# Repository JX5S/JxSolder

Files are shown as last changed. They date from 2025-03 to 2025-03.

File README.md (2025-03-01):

# Do not order the board, or blindly copy the design, there are several known issues. Namely:
- USB-PD doesn't work. I thought I could do dead battery the way I did, but it's not a good way to do it, use PA9 and PA10 instead
- Display reset needs to be wired via an RC filter to 3.3V
- Vref needs to be connected up
- Button logic is flipped - so DFU firmware upload doesn't work
- There are unidirectional transils on the input - which blow up when incorrect polarity is plugged in. Should be replaced by bidirectional transils, the ideal diodes will protect the input
- There aren't dedicated I2C pullups, which limits speed

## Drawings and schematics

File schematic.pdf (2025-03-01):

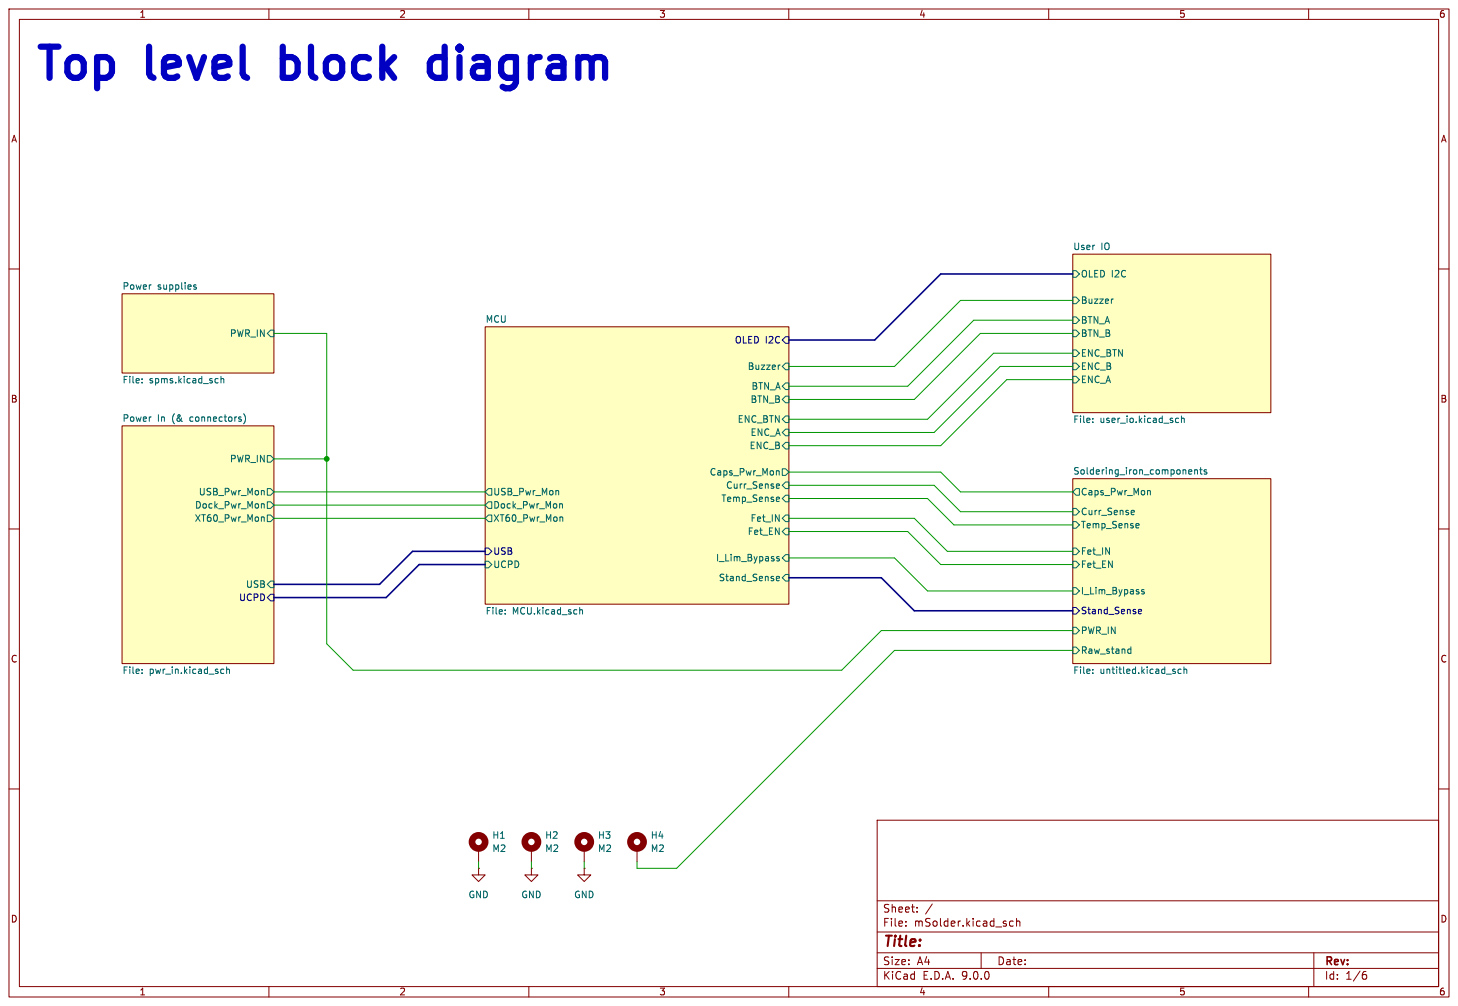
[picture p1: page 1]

H2 M2 H1 M2 Top level block diagram

Id: 1/6 Title: File: mSolder.kicad_sch Sheet: /

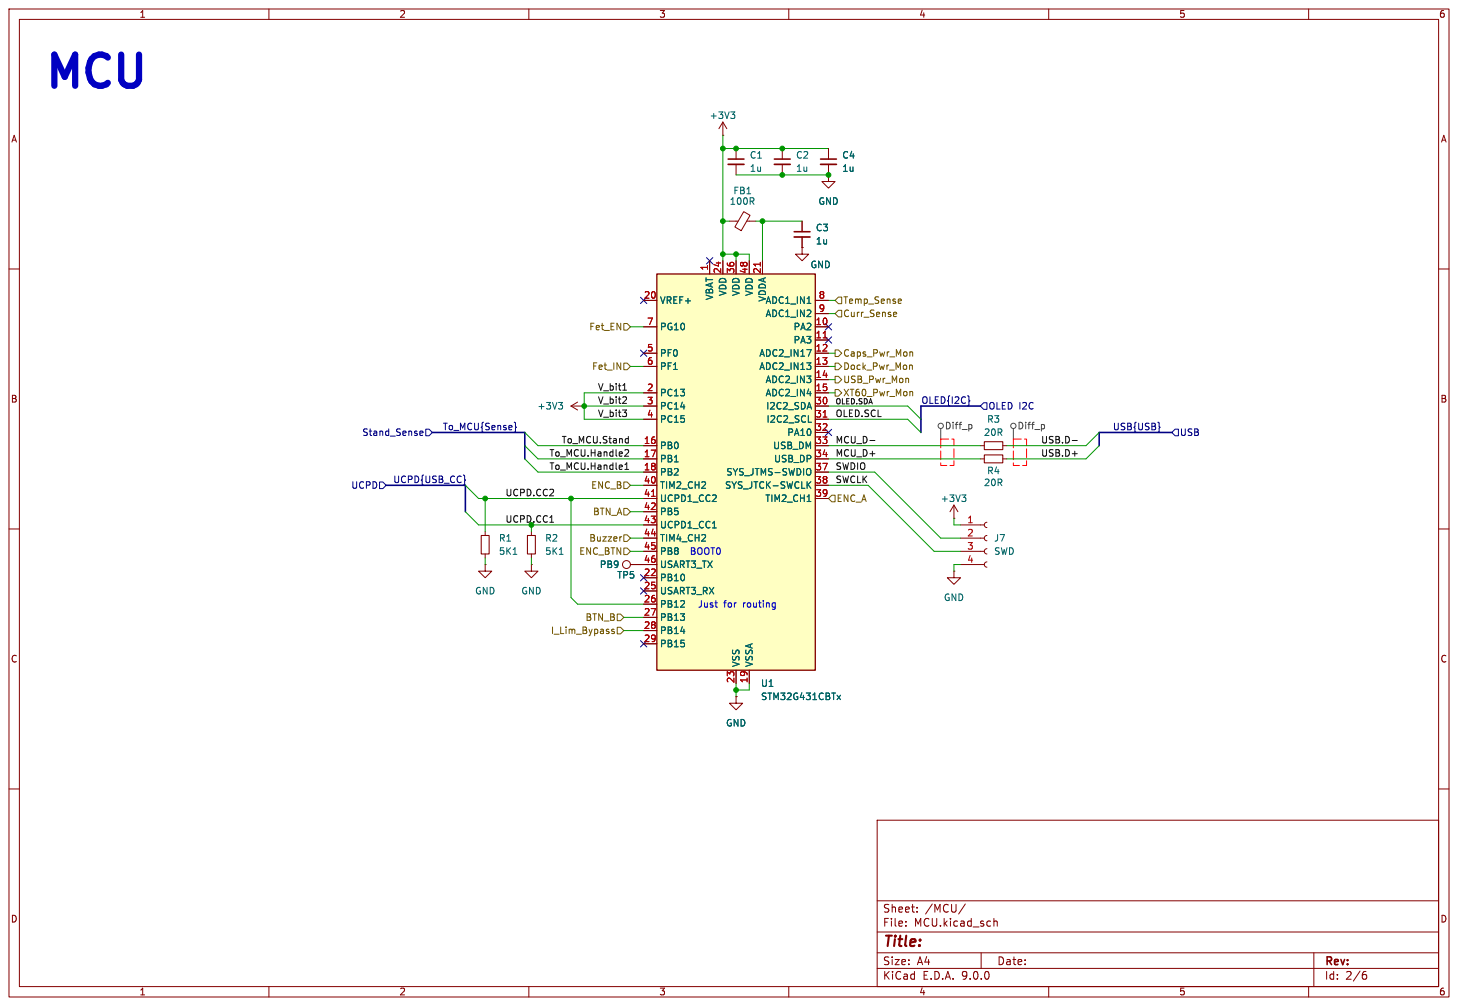
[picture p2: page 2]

1 VDD 24 VDD 36 VSS 23 VDD 48 VSSA 19 VDDA 21 ADC1_IN1 8 ADC1_IN2 9 PA2 10 PA3 11 ADC2_IN17 12 ADC2_IN13 13 ADC2_IN3 14 ADC2_IN4 15

Id: 2/6 Title: File: MCU.kicad_sch Sheet: /MCU/

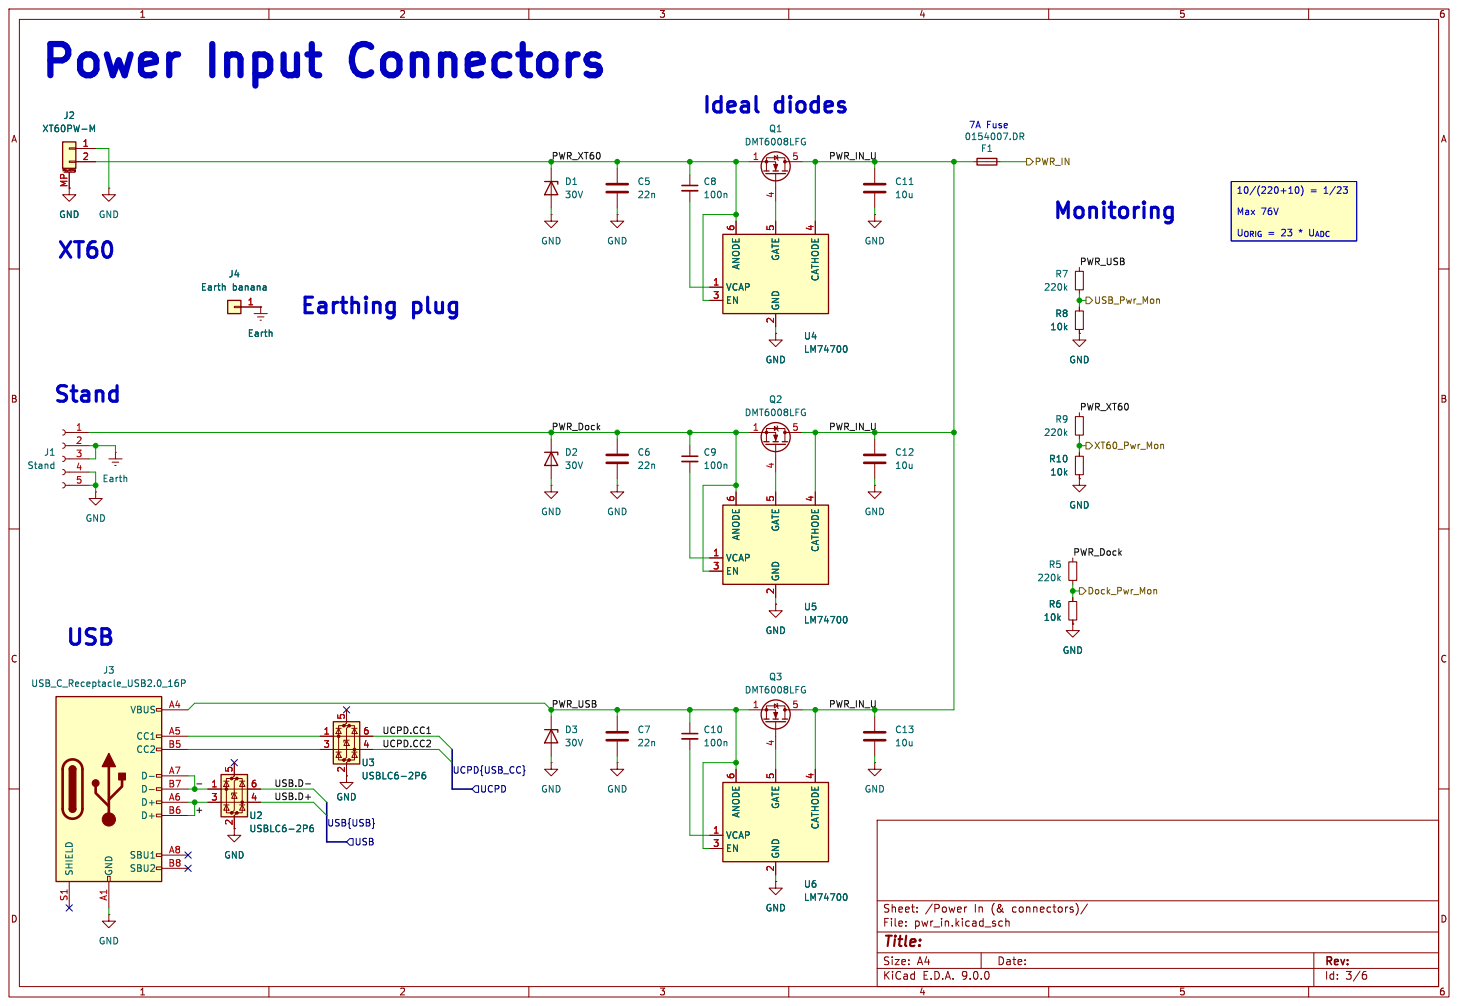
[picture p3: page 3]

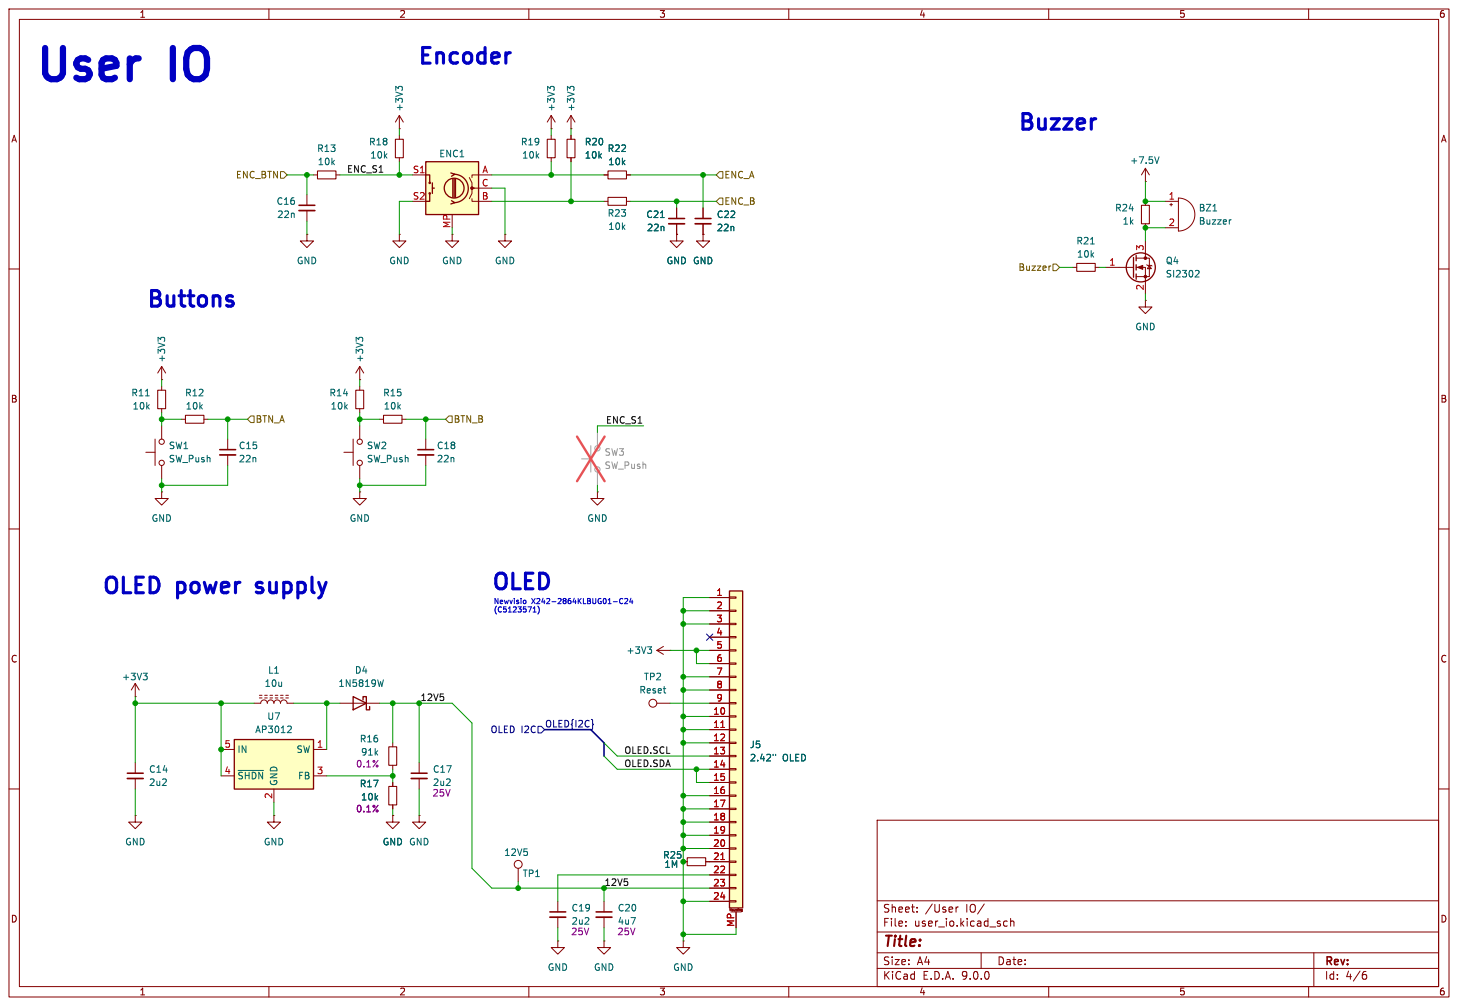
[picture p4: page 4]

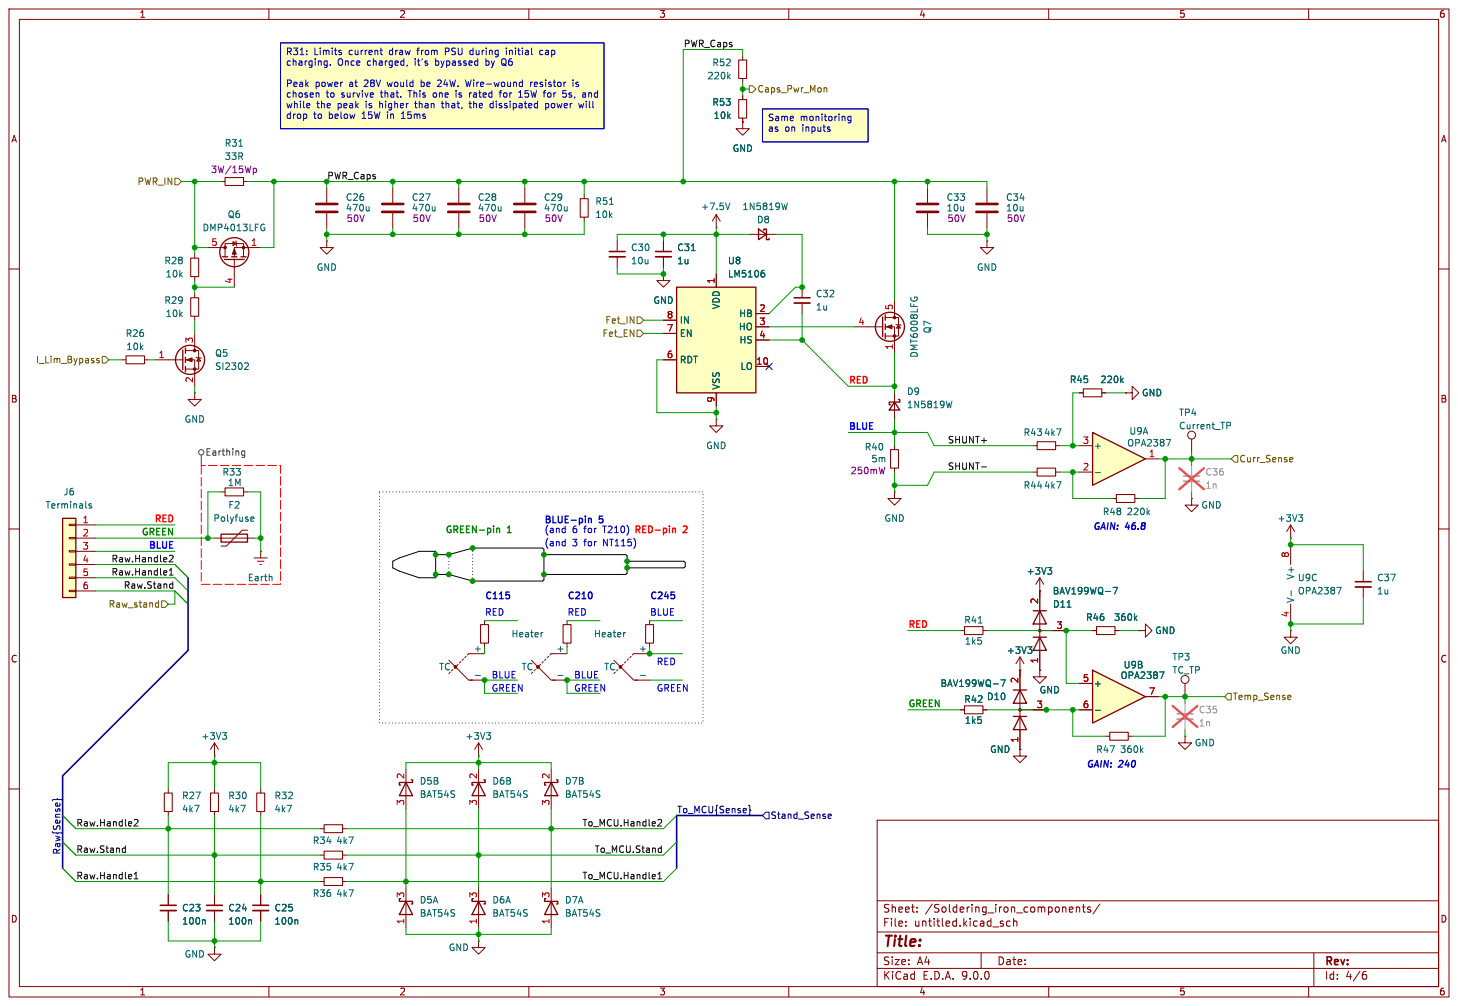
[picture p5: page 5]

Id: 4/6 Title: File: untitled.kicad_sch Sheet: /Soldering_iron_components/ R33

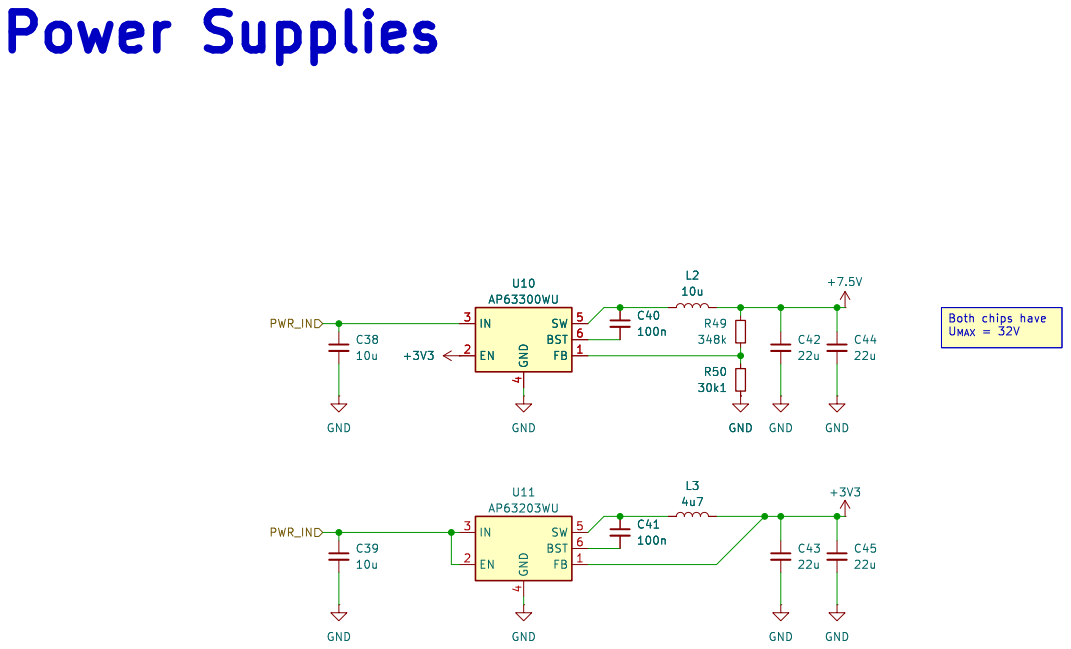
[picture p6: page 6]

Both chips have U_{MAX} = 32V Power Supplies

4 SW 5 BST 6 FB 1 U10 AP63300WU GND

4 SW 5 BST 6 FB 1 U11 AP63203WU GND

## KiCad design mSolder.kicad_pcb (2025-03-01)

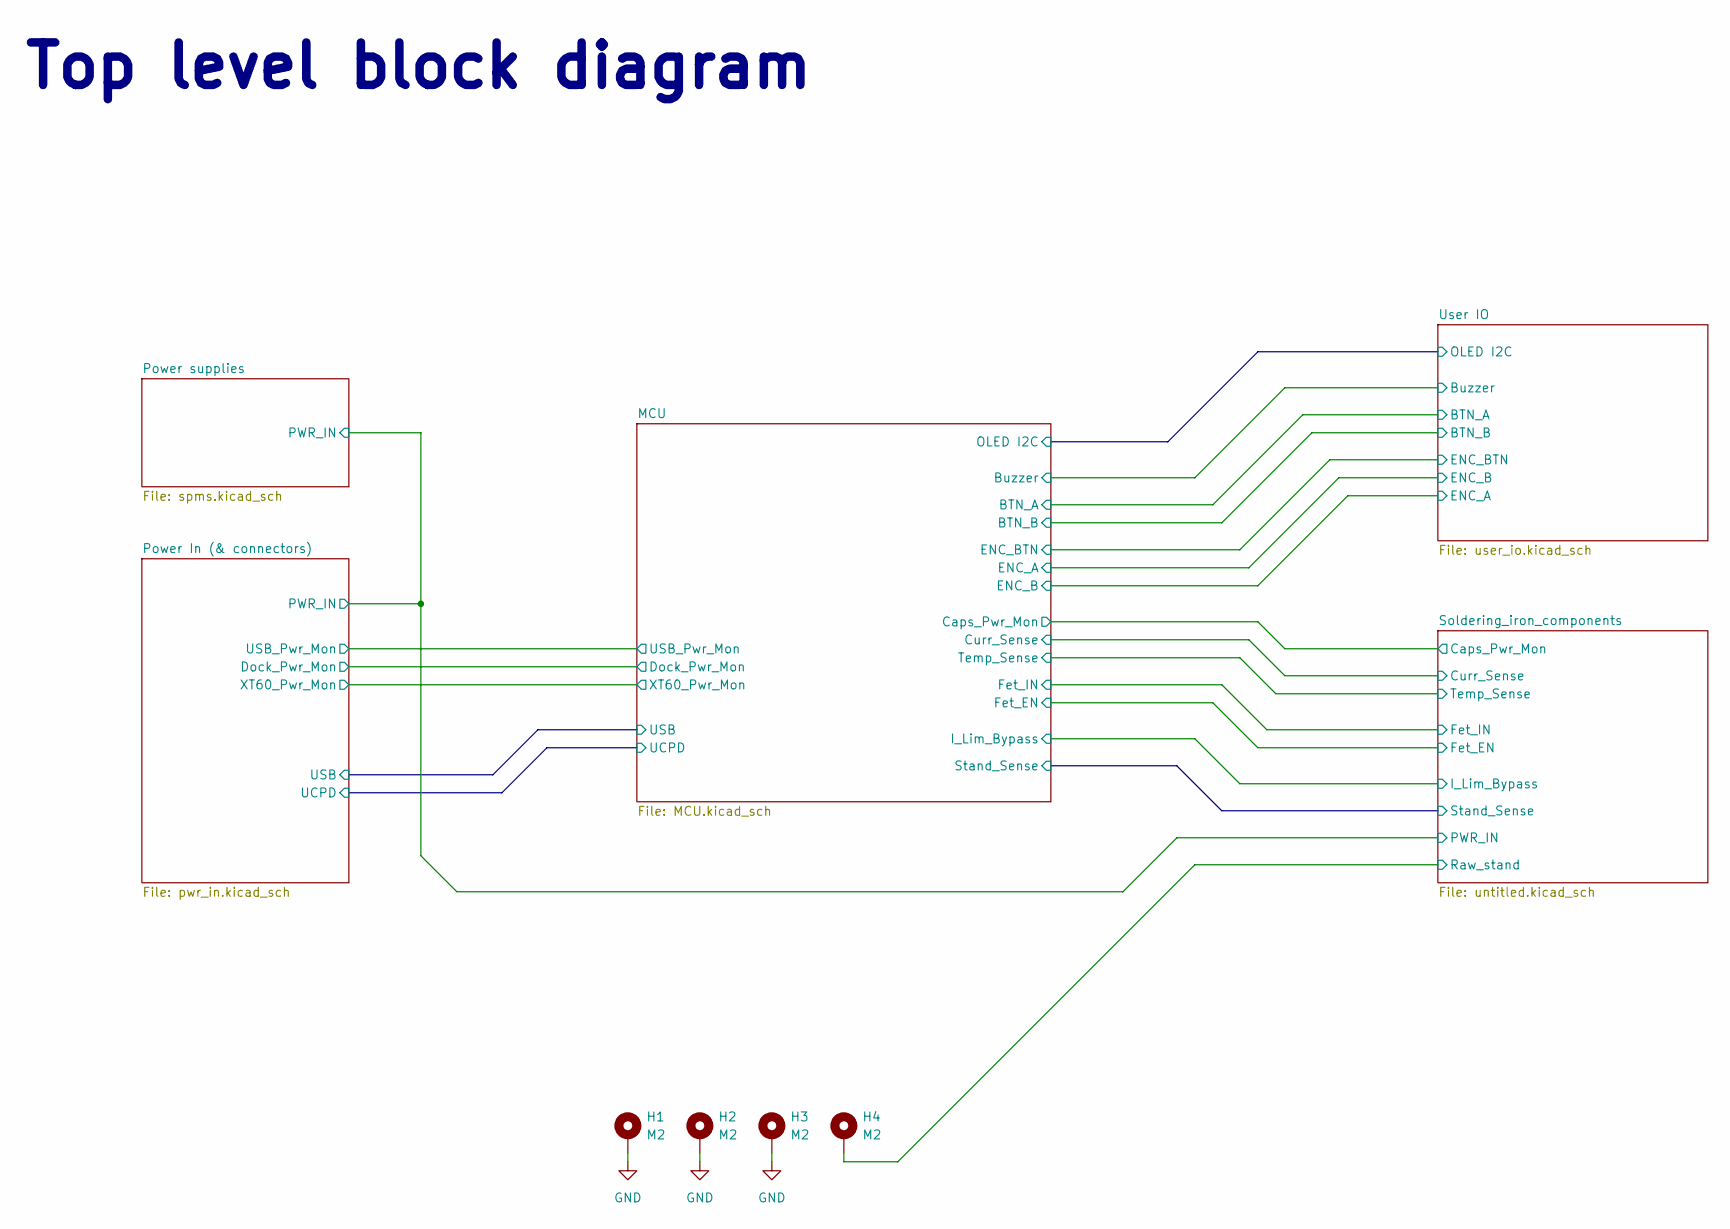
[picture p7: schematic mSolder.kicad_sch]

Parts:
H1, H2, H3, H4: M2; M2 solder nut; LCSC C3020134

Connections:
/Soldering_iron_components/Raw.Stand: H4.1; also elsewhere on the board
GND: H1.1, H2.1, H3.1; also elsewhere on the board

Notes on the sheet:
Top level block diagram

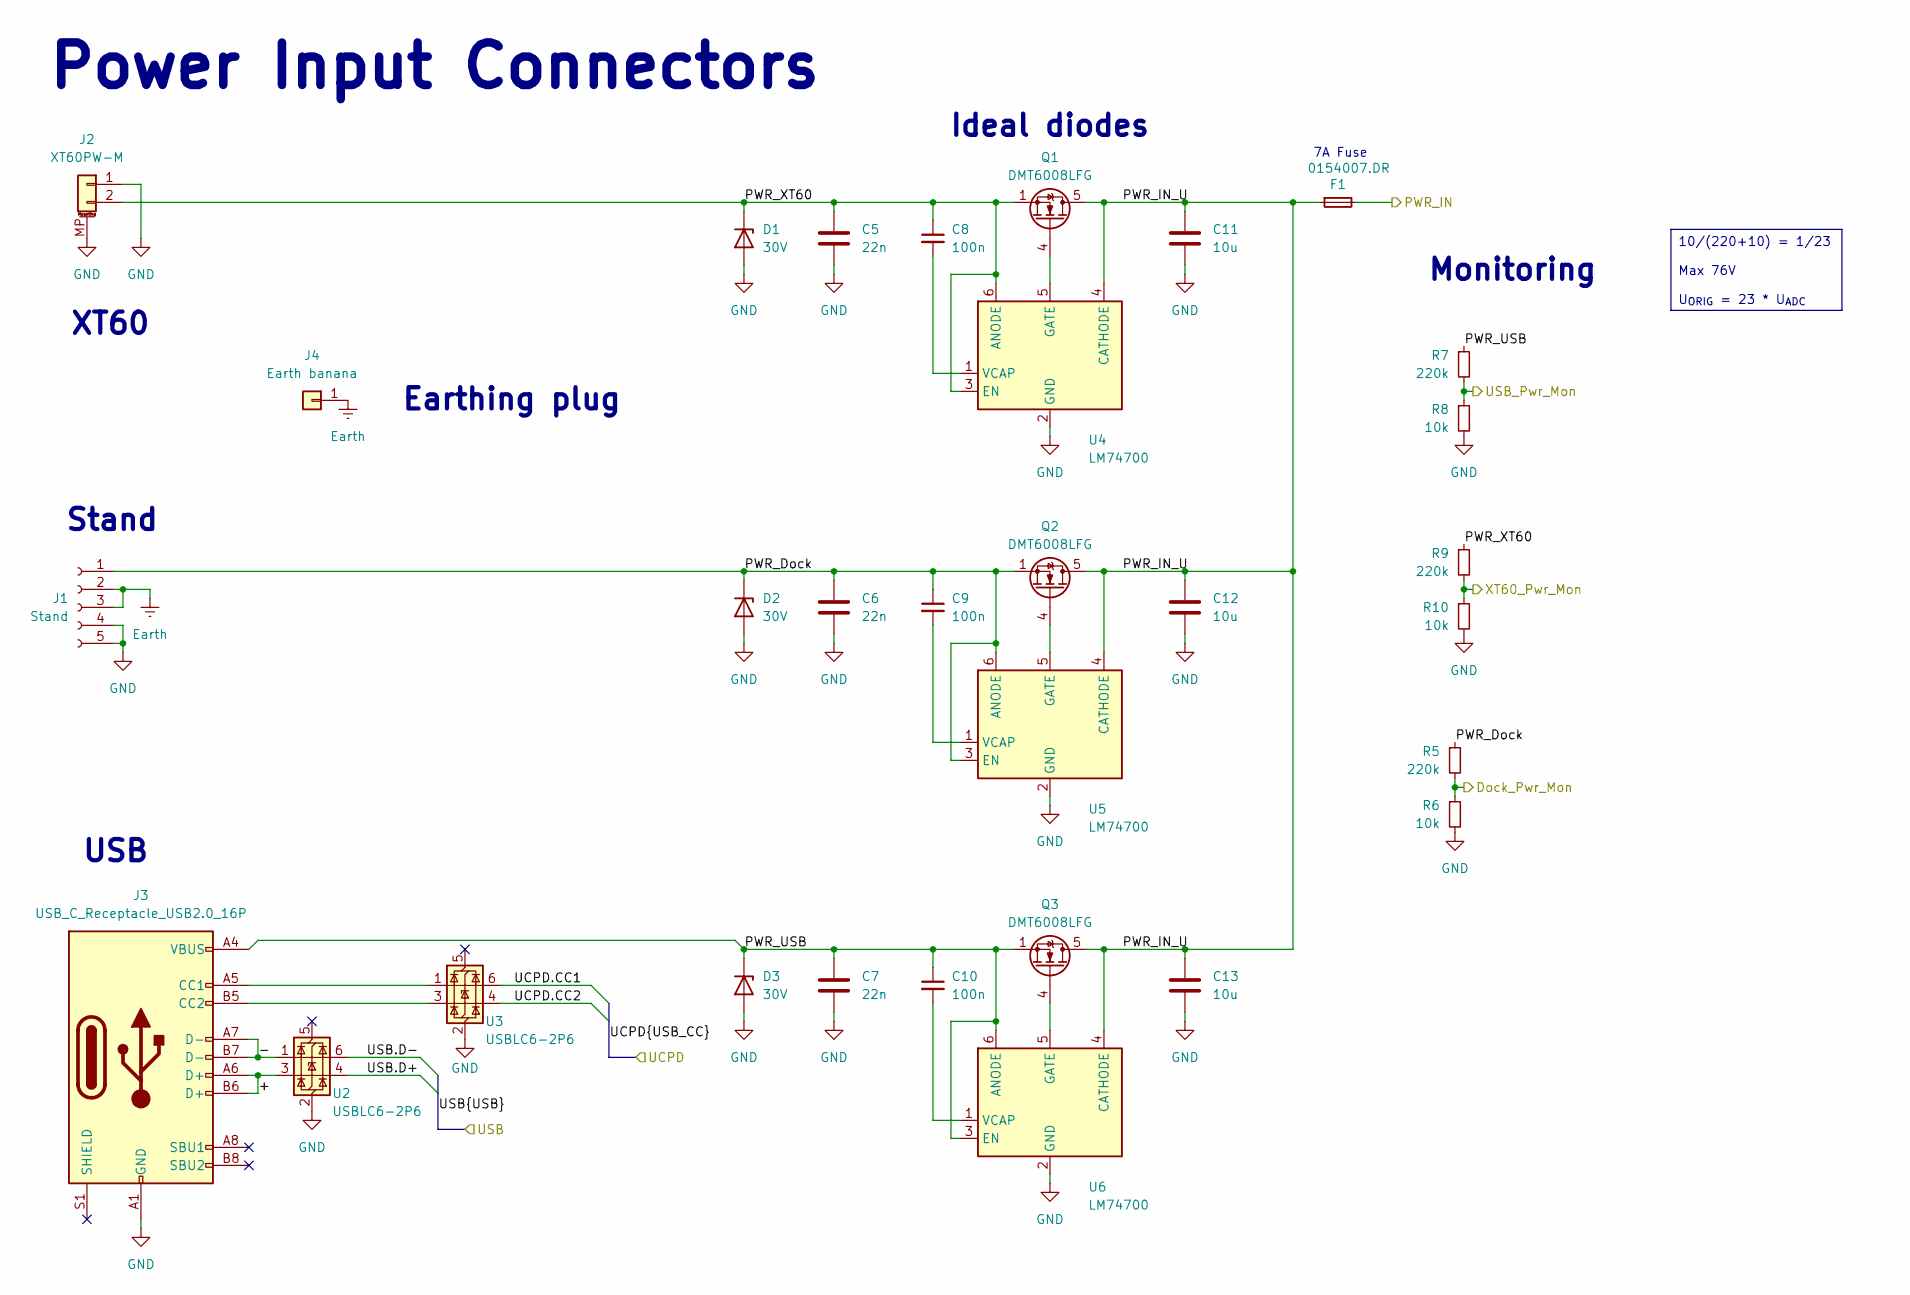
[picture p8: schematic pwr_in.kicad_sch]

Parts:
C5, C6, C7: 22n; C_0603_1608Metric; LCSC C21122
C8, C9, C10: 100n; C_0603_1608Metric; LCSC C1591
C11, C12, C13: 10u; C_1206_3216Metric; LCSC C13585
D1, D2, D3: 30V; D_SMA; LCSC C132943
F1: 0154007.DR; 0154100DR; Mouser Part Number 576-0154007.DR
J1: Stand; 1473969.1
J2: XT60PW-M; LCSC C98732
J3: USB_C_Receptacle_USB2.0_16P; USB_C_Receptacle_G-Switch_GT-USB-7010ASV; LCSC C963413
J4: Earth banana; CONN-TH_24.243.2; LCSC C7437324
Q1, Q2, Q3: DMT6008LFG; Diodes_PowerDI3333-8; LCSC C461111
R5, R7, R9: 220k; R_0603_1608Metric; LCSC C861231
R6, R8, R10: 10k; R_0603_1608Metric; LCSC C95204
U2, U3: USBLC6-2P6; SOT-666; LCSC C15999
U4, U5, U6: LM74700; SOT-23-6; LCSC C7589230

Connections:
/MCU/Dock_Pwr_Mon: R5.2, R6.1; also elsewhere on the board
/MCU/UCPD.CC1: U3.6 (I/O1); also elsewhere on the board
/MCU/UCPD.CC2: U3.4 (I/O2); also elsewhere on the board
/MCU/USB.D+: U2.4 (I/O2); also elsewhere on the board
/MCU/USB.D-: U2.6 (I/O1); also elsewhere on the board
/MCU/USB_Pwr_Mon: R7.2, R8.1; also elsewhere on the board
/MCU/XT60_Pwr_Mon: R9.2, R10.1; also elsewhere on the board
/Power In (& connectors)/+: J3.A6 (D+), J3.B6 (D+), U2.3 (I/O2)
/Power In (& connectors)/-: J3.A7 (D-), J3.B7 (D-), U2.1 (I/O1)
/Power In (& connectors)/PWR_Dock: C6.1, C9.1, D2.1 (K), J1.1, Q2.1 (S), Q2.2 (S), Q2.3 (S), R5.1, U5.3 (EN), U5.6 (ANODE)
/Power In (& connectors)/PWR_IN: F1.2; also elsewhere on the board
/Power In (& connectors)/PWR_IN_U: C11.1, C12.1, C13.1, F1.1, Q1.5 (D), Q2.5 (D), Q3.5 (D), U4.4 (CATHODE), U5.4 (CATHODE), U6.4 (CATHODE)
/Power In (& connectors)/PWR_USB: C7.1, C10.1, D3.1 (K), J3.A4 (VBUS), J3.A9 (VBUS), J3.B4 (VBUS), J3.B9 (VBUS), Q3.1 (S), Q3.2 (S), Q3.3 (S), R7.1, U6.3 (EN), U6.6 (ANODE)
/Power In (& connectors)/PWR_XT60: C5.1, C8.1, D1.1 (K), J2.2, Q1.1 (S), Q1.2 (S), Q1.3 (S), R9.1, U4.3 (EN), U4.6 (ANODE)
Earth: J1.2, J1.3, J4.1; also elsewhere on the board
GND: C5.2, C6.2, C7.2, C11.2, C12.2, C13.2, D1.2 (A), D2.2 (A), D3.2 (A), J1.4, J1.5, J2.1, J2.MP (MountPin), J3.A1 (GND), J3.A12 (GND), J3.B1 (GND), J3.B12 (GND), R6.2, R8.2, R10.2, U2.2 (GND), U3.2 (GND), U4.2 (GND), U5.2 (GND), U6.2 (GND); also elsewhere on the board
unnamed: J3.A5 (CC1), U3.1 (I/O1)
unnamed: J3.B5 (CC2), U3.3 (I/O2)
unnamed: Q1.4 (G), U4.5 (GATE)
unnamed: Q2.4 (G), U5.5 (GATE)
unnamed: Q3.4 (G), U6.5 (GATE)
unnamed: C8.2, U4.1 (VCAP)
unnamed: C9.2, U5.1 (VCAP)
unnamed: C10.2, U6.1 (VCAP)

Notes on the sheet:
Monitoring
Ideal diodes
Power Input Connectors
XT60
Earthing plug
USB
Stand
7A Fuse
10/(220+10) = 1/23 Max 76V U_{ORIG} = 23 * U_{ADC}

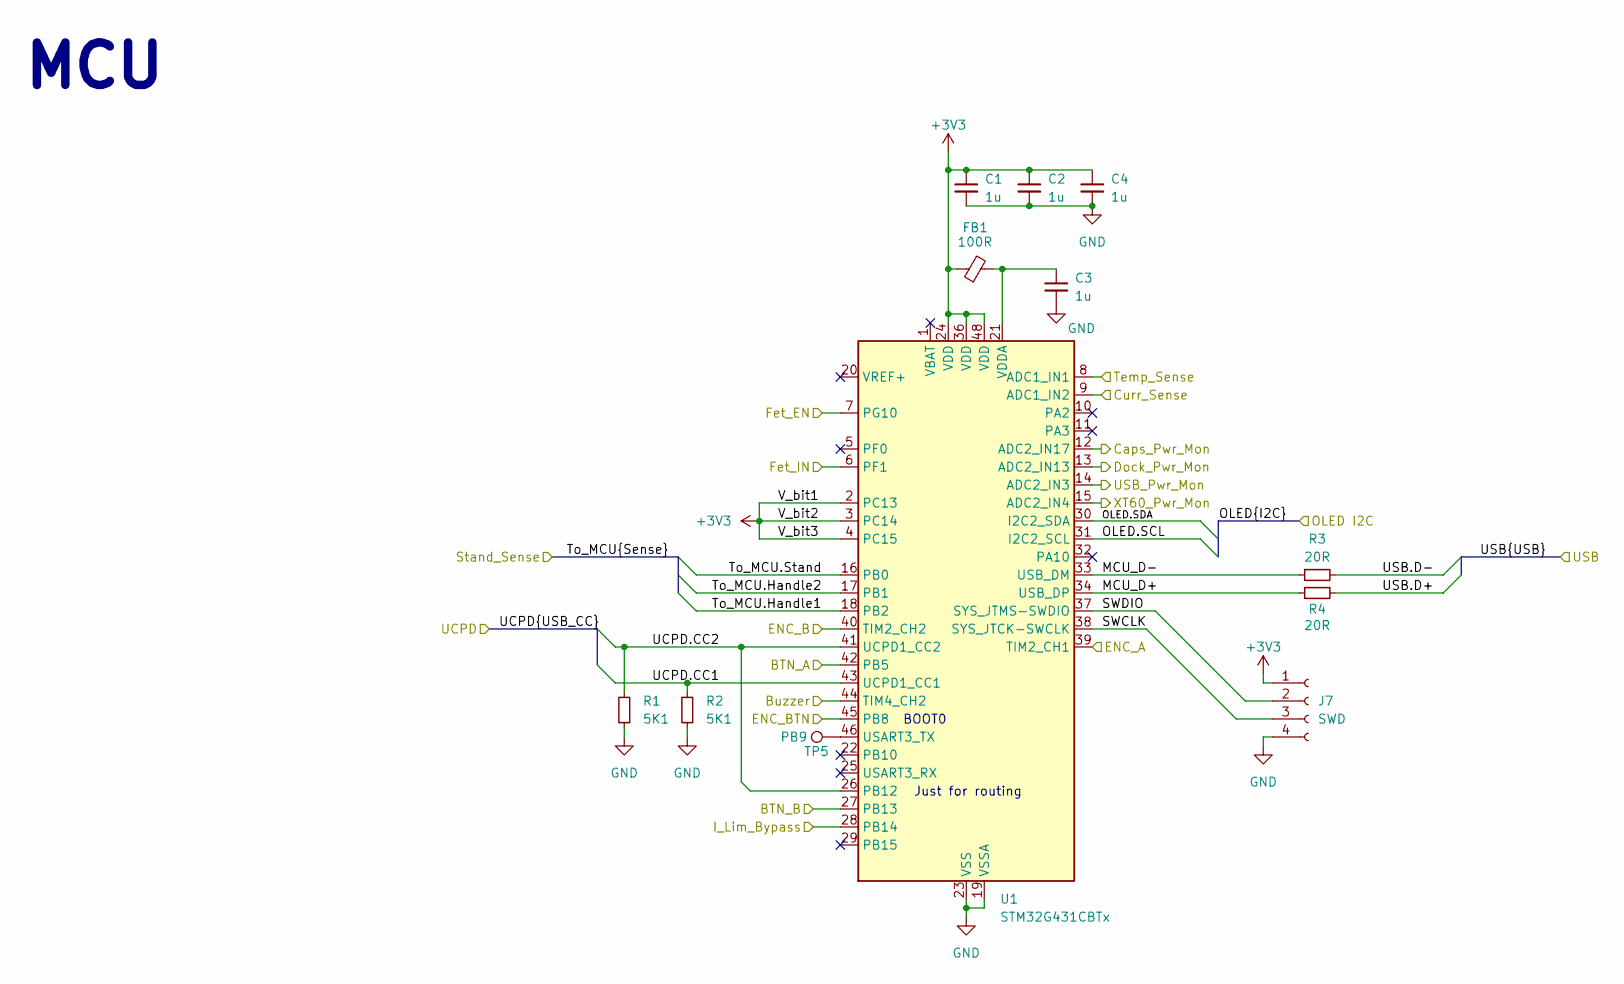
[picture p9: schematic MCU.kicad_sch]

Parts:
C1, C2, C3, C4: 1u; C_0603_1608Metric; LCSC C15849
FB1: 100R; R_0603_1608Metric; LCSC C107332
J7: SWD; PinHeader_1x04_P2.54mm_Vertical; LCSC C2691448
R1, R2: 5K1; R_0603_1608Metric; LCSC C105580
R3, R4: 20R; R_0603_1608Metric; LCSC C125758
TP5: PB9; TestPoint_Pad_D1.0mm
U1: STM32G431CBTx; LQFP-48_7x7mm_P0.5mm; LCSC C529355

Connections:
+3V3: C1.1, C2.1, C4.1, FB1.1, J7.1, U1.2 (PC13), U1.3 (PC14), U1.4 (PC15), U1.24 (VDD), U1.36 (VDD), U1.48 (VDD); also elsewhere on the board
/MCU/BTN_A: U1.42 (PB5); also elsewhere on the board
/MCU/BTN_B: U1.27 (PB13); also elsewhere on the board
/MCU/Buzzer: U1.44 (PB7); also elsewhere on the board
/MCU/Caps_Pwr_Mon: U1.12 (ADC2_IN17); also elsewhere on the board
/MCU/Curr_Sense: U1.9 (ADC1_IN2); also elsewhere on the board
/MCU/Dock_Pwr_Mon: U1.13 (ADC2_IN13); also elsewhere on the board
/MCU/ENC_A: U1.39 (TIM2_CH1); also elsewhere on the board
/MCU/ENC_B: U1.40 (TIM2_CH2); also elsewhere on the board
/MCU/ENC_BTN: U1.45 (PB8); also elsewhere on the board
/MCU/Fet_EN: U1.7 (PG10); also elsewhere on the board
/MCU/Fet_IN: U1.6 (PF1); also elsewhere on the board
/MCU/I_Lim_Bypass: U1.28 (PB14); also elsewhere on the board
/MCU/MCU_D+: R4.1, U1.34 (USB_DP)
/MCU/MCU_D-: R3.1, U1.33 (USB_DM)
/MCU/OLED.SCL: U1.31 (I2C2_SCL); also elsewhere on the board
/MCU/OLED.SDA: U1.30 (I2C2_SDA); also elsewhere on the board
/MCU/SWCLK: J7.3, U1.38 (SYS_JTCK-SWCLK)
/MCU/SWDIO: J7.2, U1.37 (SYS_JTMS-SWDIO)
/MCU/Temp_Sense: U1.8 (ADC1_IN1); also elsewhere on the board
/MCU/To_MCU.Handle1: U1.18 (PB2); also elsewhere on the board
/MCU/To_MCU.Handle2: U1.17 (PB1); also elsewhere on the board
/MCU/To_MCU.Stand: U1.16 (PB0); also elsewhere on the board
/MCU/UCPD.CC1: R2.2, U1.43 (UCPD1_CC1); also elsewhere on the board
/MCU/UCPD.CC2: R1.2, U1.26 (PB12), U1.41 (UCPD1_CC2); also elsewhere on the board
/MCU/USB.D+: R4.2; also elsewhere on the board
/MCU/USB.D-: R3.2; also elsewhere on the board
/MCU/USB_Pwr_Mon: U1.14 (ADC2_IN3); also elsewhere on the board
/MCU/XT60_Pwr_Mon: U1.15 (ADC2_IN4); also elsewhere on the board
GND: C1.2, C2.2, C3.2, C4.2, J7.4, R1.1, R2.1, U1.19 (VSSA), U1.23 (VSS), U1.35 (VSS), U1.47 (VSS); also elsewhere on the board
unnamed: TP5.1, U1.46 (USART3_TX)
unnamed: C3.1, FB1.2, U1.21 (VDDA)

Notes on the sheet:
BOOT0
Just for routing
MCU

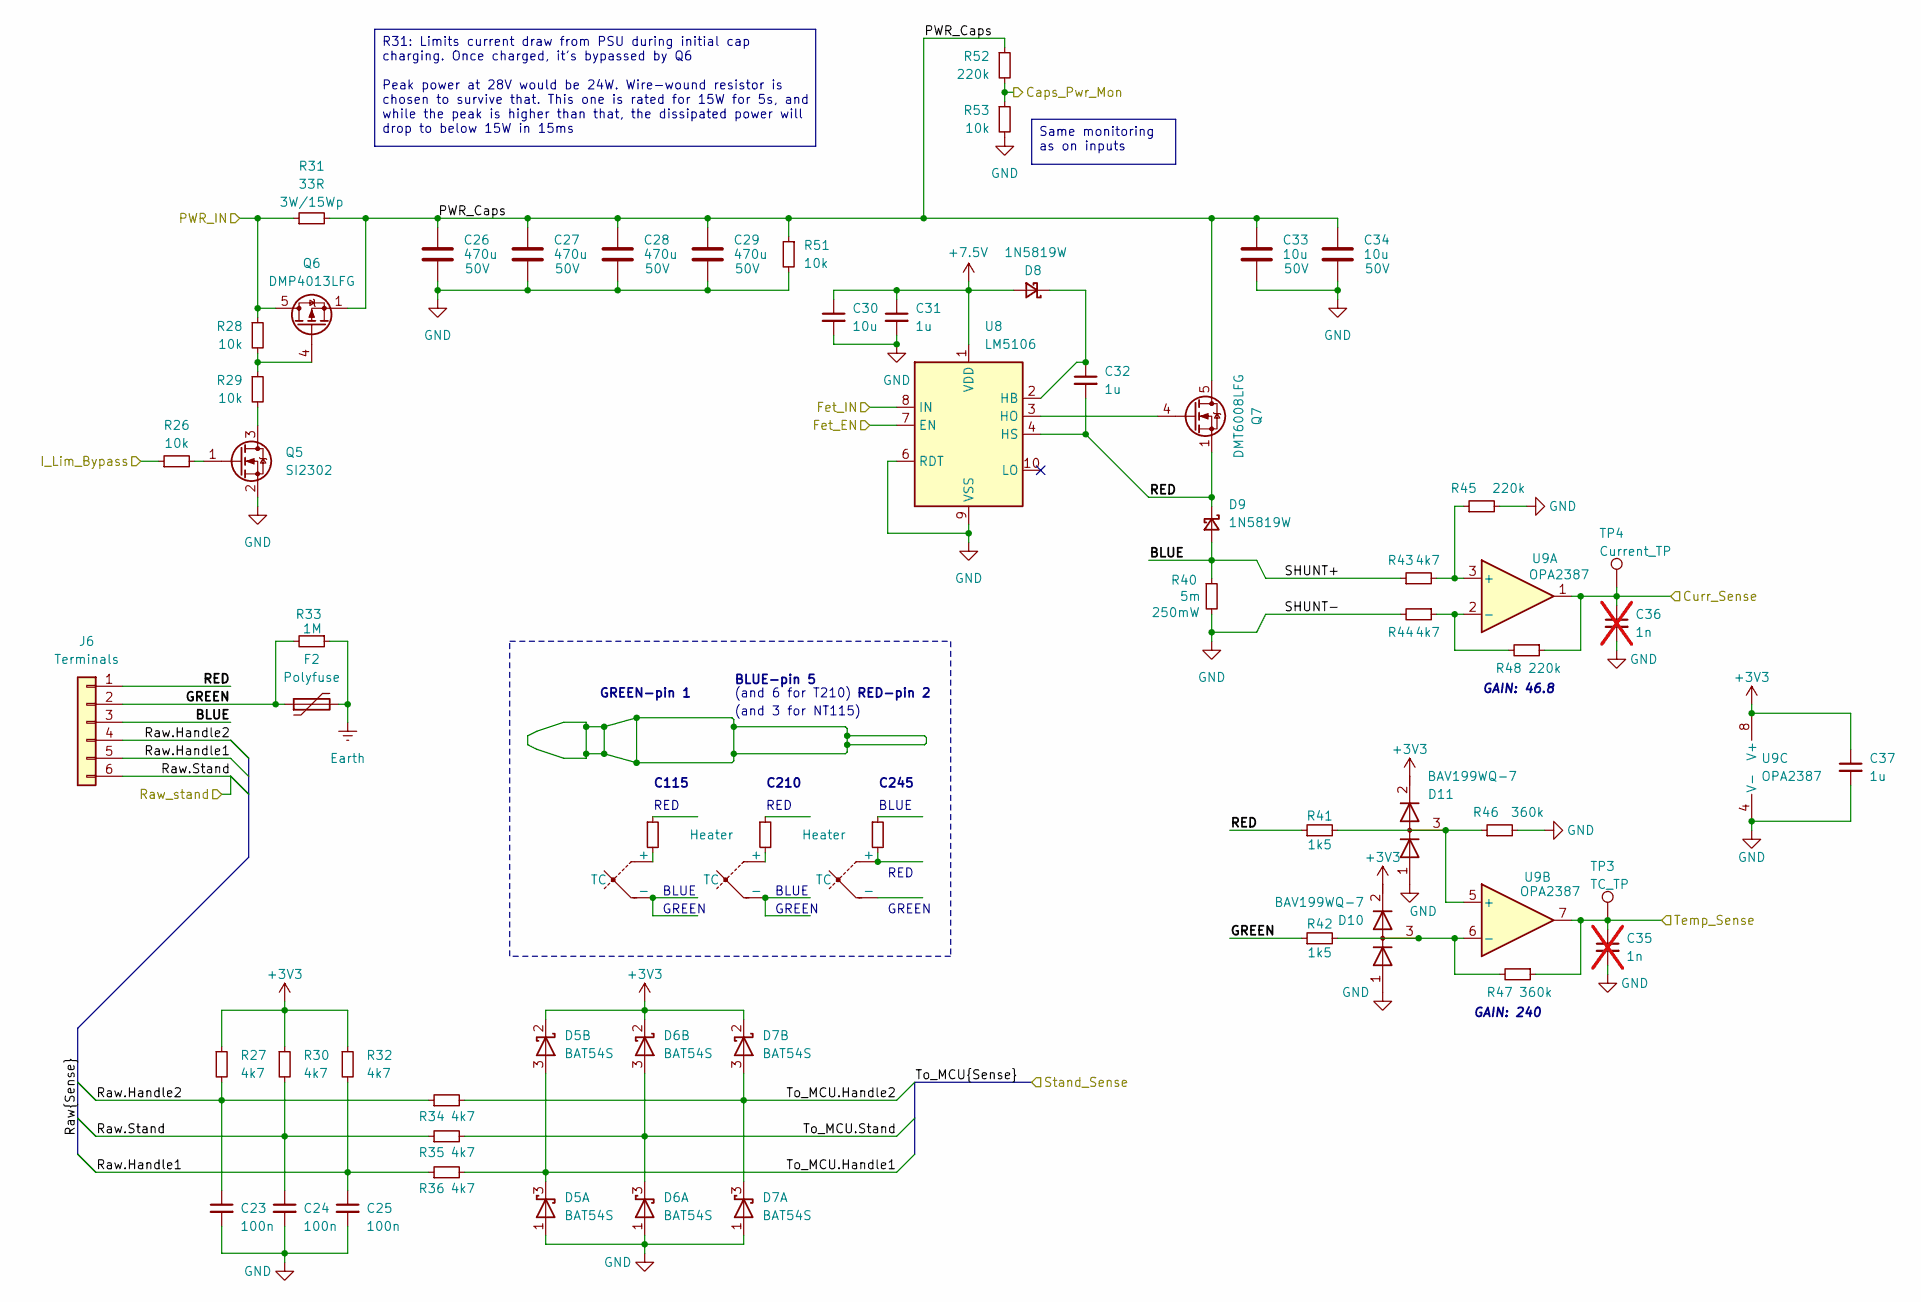
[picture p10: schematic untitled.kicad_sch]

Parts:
C23, C24, C25: 100n; C_0603_1608Metric; Manufacturer_Part_Number C0603C104J5RACTU; Mouser Part Number 80-C0603C104J5R
C26, C27, C28, C29: 470u; CP_Radial_D12.5mm_P5.00mm_L20_Laid on side; Voltage 50V; LCSC C1586027
C30: 10u; C_1206_3216Metric; LCSC C13585
C31, C32, C37: 1u; C_0603_1608Metric; LCSC C15849
C33, C34: 10u; C_1210_3225Metric; Voltage 50V; LCSC C126612
C35, C36: 1n; C_0603_1608Metric; Manufacturer_Part_Number C0603C102K3GAC; Mouser Part Number 80-C0603C102K3G; not fitted
D5, D6, D7: BAT54S; SOT-23; LCSC C47546
D8, D9: 1N5819W; D_SOD-123; LCSC C727115
D10, D11: BAV199WQ-7; SOT-323_SC-70; Mouser Part Number 621-BAV199WQ-7
F2: Polyfuse; Fuse_2512_6332Metric; LCSC C41364424
J6: Terminals; screw_terminal_6x3.81; LCSC C5143696
Q5: SI2302; TSOT-23; LCSC C5310967
Q6: DMP4013LFG; Diodes_PowerDI3333-8; LCSC C460203
Q7: DMT6008LFG; Diodes_PowerDI3333-8; LCSC C461111
R26, R28, R29, R51, R53: 10k; R_0603_1608Metric; LCSC C95204
R27, R30, R32, R34, R35, R36, R43, R44: 4k7; R_0603_1608Metric; Manufacturer_Part_Number ERJ-3RBD4701V; Mouser Part Number 667-ERJ-3RBD4701V
R31: 33R; R_TyOHM_SMW_3W; LCSC C2937341
R33: 1M; R_2512_6332Metric; LCSC C276335
R37, R38: Heater
R39: Heater 2 OHM
R40: 5m; R_1206_3216Metric; LCSC C875583
R41, R42: 1k5; R_0603_1608Metric; Manufacturer_Part_Number ERJ-H3ED1501V; Mouser Part Number 667-ERJ-H3ED1501V
R45, R48: 220k; R_0603_1608Metric; Manufacturer_Part_Number ERJ-3RED2203V; Mouser Part Number 667-ERJ-3RED2203V
R46, R47: 360k; R_0603_1608Metric; Manufacturer_Part_Number ERJ-3RED3603V; Mouser Part Number 667-ERJ-3RED3603V
R52: 220k; R_0603_1608Metric; LCSC C861231
TC1, TC2, TC3: TC
TP3: TC_TP; TestPoint_Pad_D1.0mm
TP4: Current_TP; TestPoint_Pad_D1.0mm
U8: LM5106; VSSOP-10_3x3mm_P0.5mm; LCSC C91879
U9: OPA2387; VSSOP-8_3x3mm_P0.65mm; LCSC C2861203

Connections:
+3V3: C37.1, D5.2 (K), D6.2 (K), D7.2 (K), D10.2, D11.2, R27.1, R30.1, R32.1, U9.8 (V+); also elsewhere on the board
+7.5V: C30.1, C31.1, D8.2 (A), U8.1 (VDD); also elsewhere on the board
/MCU/Caps_Pwr_Mon: R52.2, R53.1; also elsewhere on the board
/MCU/Curr_Sense: C36.1, R48.1, TP4.1, U9.1; also elsewhere on the board
/MCU/Fet_EN: U8.7 (EN); also elsewhere on the board
/MCU/Fet_IN: U8.8 (IN); also elsewhere on the board
/MCU/I_Lim_Bypass: R26.1; also elsewhere on the board
/MCU/Temp_Sense: C35.1, R47.1, TP3.1, U9.7; also elsewhere on the board
/MCU/To_MCU.Handle1: D5.3 (K), R36.2; also elsewhere on the board
/MCU/To_MCU.Handle2: D7.3 (K), R34.2; also elsewhere on the board
/MCU/To_MCU.Stand: D6.3 (K), R35.2; also elsewhere on the board
/Power In (& connectors)/PWR_IN: Q6.5 (D), R28.1, R31.1; also elsewhere on the board
/Soldering_iron_components/BLUE: D9.2 (A), J6.3, R40.1, R43.1
/Soldering_iron_components/GREEN: F2.1, J6.2, R33.2, R42.1
/Soldering_iron_components/PWR_Caps: C26.1, C27.1, C28.1, C29.1, C33.1, C34.1, Q6.1 (S), Q6.2 (S), Q6.3 (S), Q7.5 (D), R31.2, R51.1, R52.1
/Soldering_iron_components/RED: C32.2, D9.1 (K), J6.1, Q7.1 (S), Q7.2 (S), Q7.3 (S), R41.1, U8.4 (HS)
/Soldering_iron_components/Raw.Handle1: C25.1, J6.5, R32.2, R36.1
/Soldering_iron_components/Raw.Handle2: C23.1, J6.4, R27.2, R34.1
/Soldering_iron_components/Raw.Stand: C24.1, J6.6, R30.2, R35.1; also elsewhere on the board
Earth: F2.2, R33.1; also elsewhere on the board
GND: C23.2, C24.2, C25.2, C26.2, C27.2, C28.2, C29.2, C30.2, C31.2, C33.2, C34.2, C35.2, C36.2, C37.2, D5.1 (A), D6.1 (A), D7.1 (A), D10.1, D11.1, Q5.2 (S), R40.2, R44.2, R45.2, R46.2, R51.2, R53.2, U8.6 (RDT), U8.9 (VSS), U9.4 (V-); also elsewhere on the board
unnamed: C32.1, D8.1 (K), U8.2 (HB)
unnamed: Q5.3 (D), R29.2
unnamed: Q5.1 (G), R26.2
unnamed: Q6.4 (G), R28.2, R29.1
unnamed: Q7.4 (G), U8.3 (HO)
unnamed: R37.2, TC1.1 (+)
unnamed: R38.2, TC2.1 (+)
unnamed: R39.2, TC3.1 (+)
unnamed: R43.2, R45.1, U9.3 (+)
unnamed: R44.1, R48.2, U9.2 (-)
unnamed: D11.3, R41.2, R46.1, U9.5 (+)
unnamed: D10.3, R42.2, R47.2, U9.6 (-)

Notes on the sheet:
BLUE
RED-pin 2
BLUE-pin 5
C245
GREEN
(and 3 for NT115)
GAIN: 240
RED
GREEN-pin 1
RED
GAIN: 46.8
C210
C115
(and 6 for T210)
Same monitoring as on inputs
R31: Limits current draw from PSU during initial cap charging. Once charged, it's bypassed by Q6 Peak power at 28V would be 24W. Wire-wound resistor is chosen to survive that. This one is rated for 15W for 5s, and while the peak is higher than that, the dissipated power will drop to below 15W in 15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

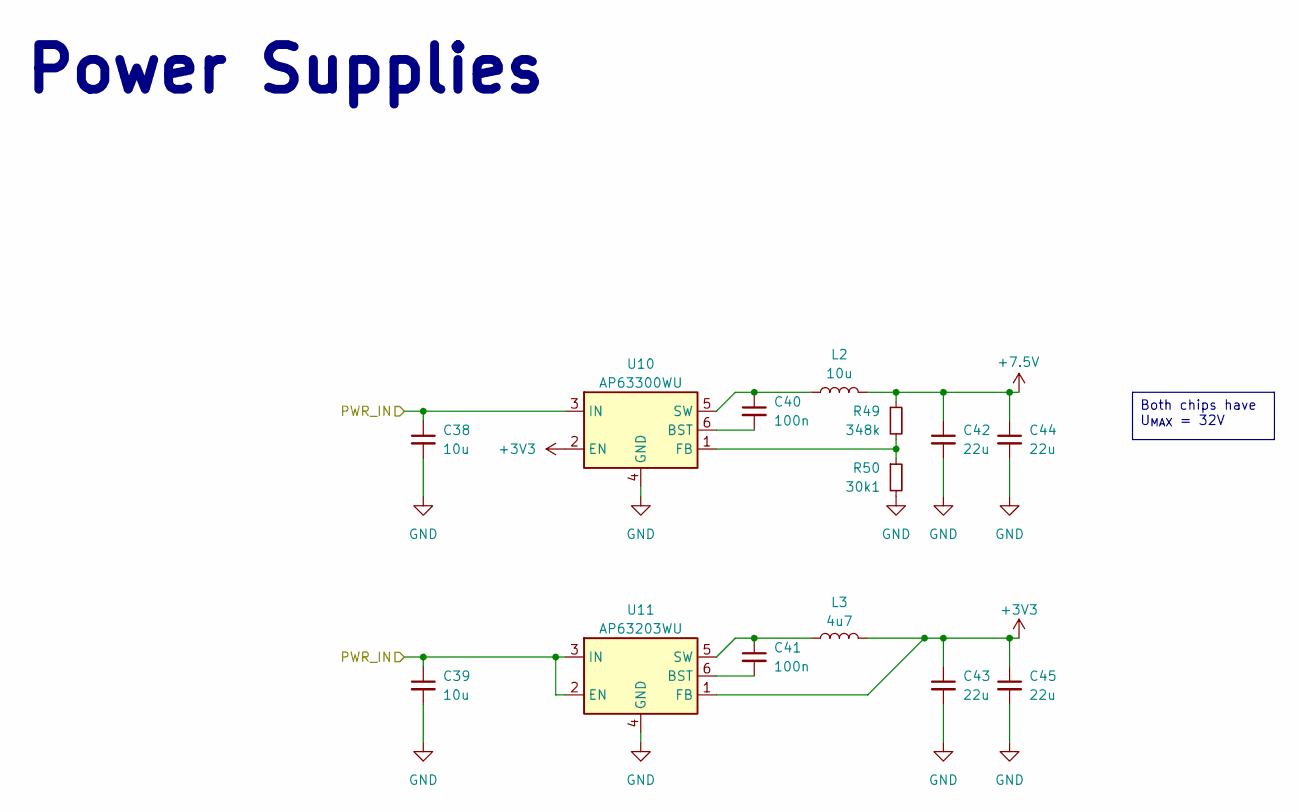
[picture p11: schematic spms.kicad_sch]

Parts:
C38, C39: 10u; C_1206_3216Metric; LCSC C13585
C40, C41: 100n; C_0603_1608Metric; LCSC C1591
C42, C43, C44, C45: 22u; C_1206_3216Metric; LCSC C77091
L2: 10u; L_Chilisin_BMRA00040420; LCSC C177242
L3: 4u7; L_Chilisin_BMRA00040420; LCSC C167208
R49: 348k; R_0603_1608Metric; LCSC C227828
R50: 30k1; R_0603_1608Metric; LCSC C137745
U10: AP63300WU; TSOT-23-6; LCSC C2158012
U11: AP63203WU; TSOT-23-6; LCSC C780769

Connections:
+3V3: C43.1, C45.1, L3.2, U10.2 (EN), U11.1 (FB); also elsewhere on the board
+7.5V: C42.1, C44.1, L2.2, R49.1; also elsewhere on the board
/Power In (& connectors)/PWR_IN: C38.1, C39.1, U10.3 (IN), U11.2 (EN), U11.3 (IN); also elsewhere on the board
GND: C38.2, C39.2, C42.2, C43.2, C44.2, C45.2, R50.2, U10.4 (GND), U11.4 (GND); also elsewhere on the board
unnamed: C40.2, U10.6 (BST)
unnamed: R49.2, R50.1, U10.1 (FB)
unnamed: C40.1, L2.1, U10.5 (SW)
unnamed: C41.2, U11.6 (BST)
unnamed: C41.1, L3.1, U11.5 (SW)

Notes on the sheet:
Power Supplies
Both chips have U_{MAX} = 32V

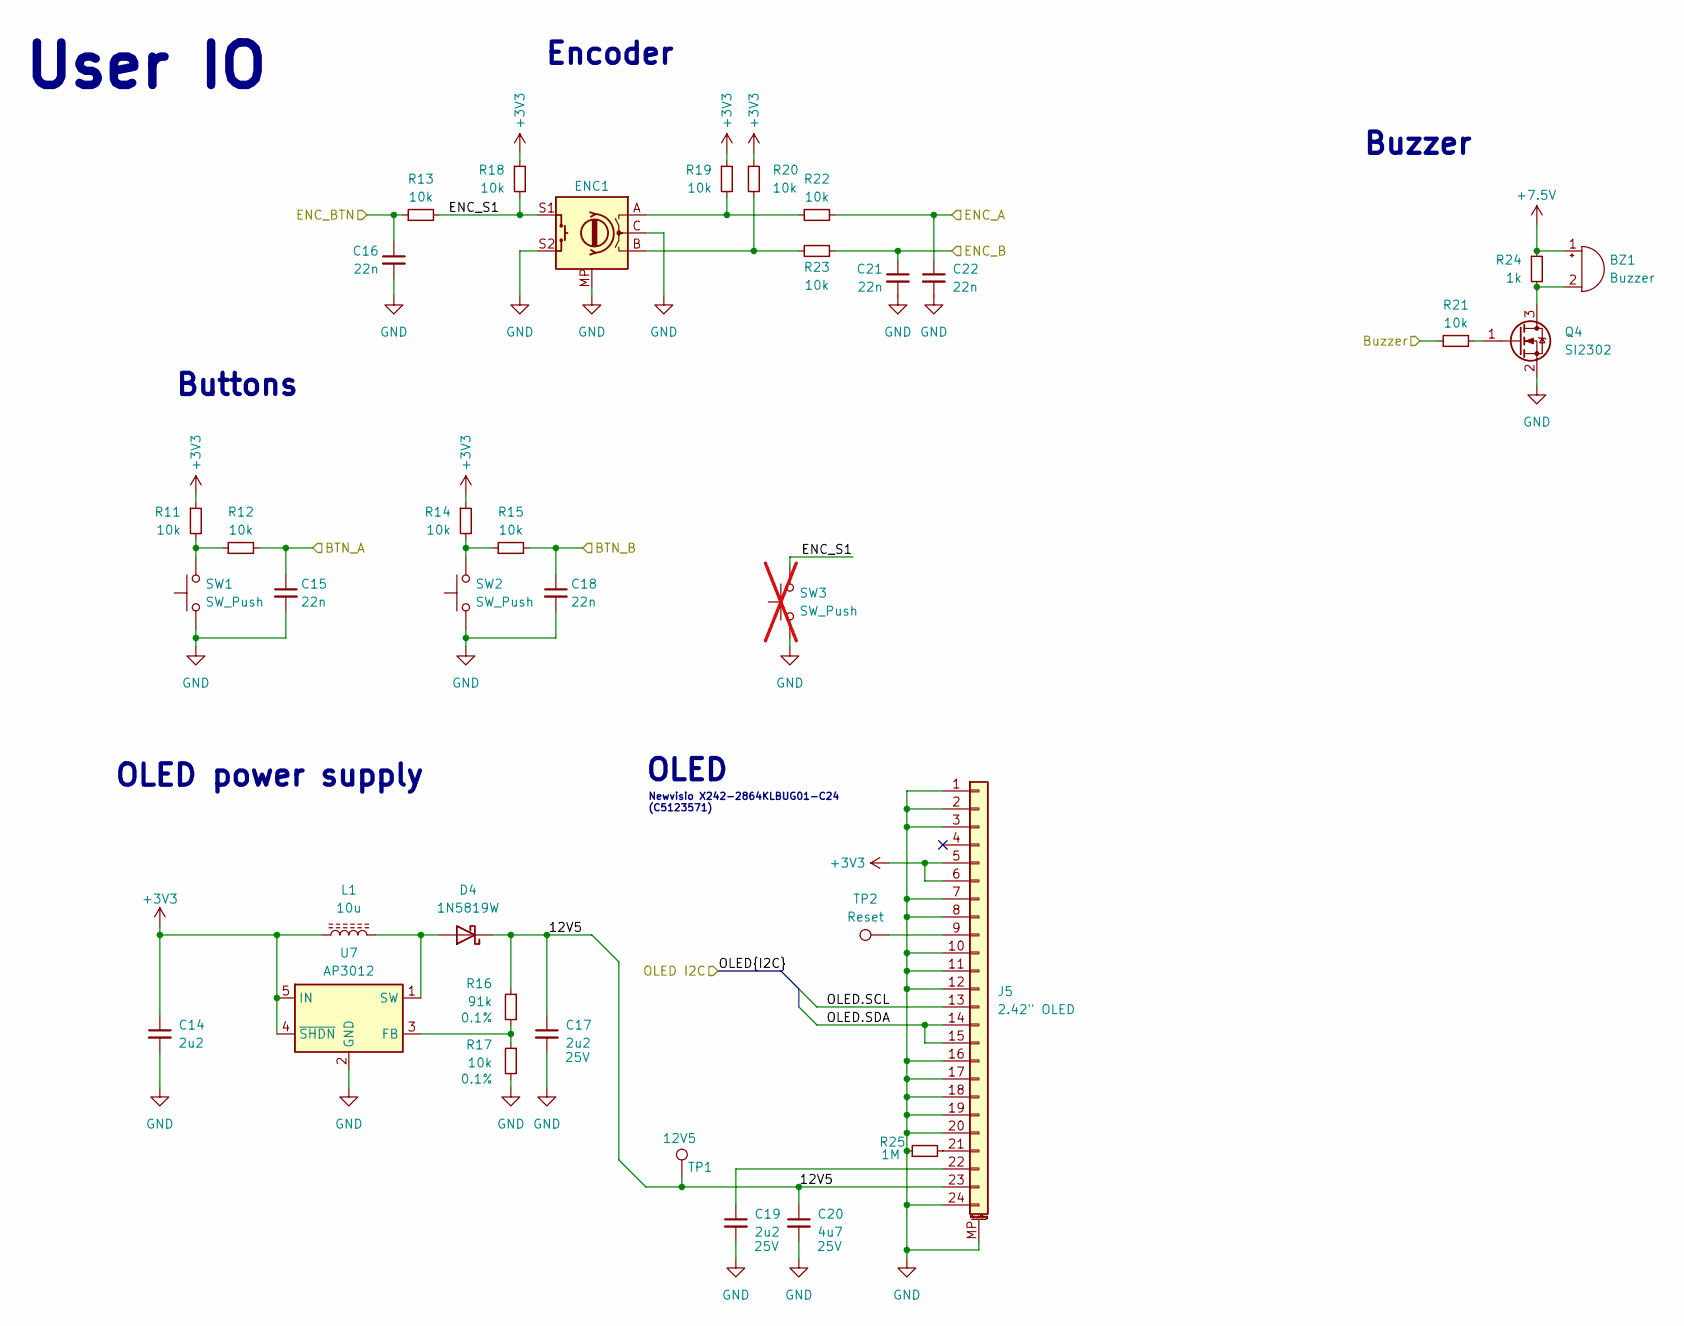
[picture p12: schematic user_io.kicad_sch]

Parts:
BZ1: Buzzer; Buzzer_Murata_PKMCS0909E; LCSC C910763
C14: 2u2; C_0603_1608Metric; LCSC C57895
C15, C16, C18, C21, C22: 22n; C_0603_1608Metric; LCSC C21122
C17, C19: 2u2; C_0603_1608Metric; Voltage 25V; LCSC C57895
C20: 4u7; C_0603_1608Metric; Voltage 25V; LCSC C69335
D4: 1N5819W; D_SOD-123; LCSC C727115
ENC1: RotaryEncoder_Switch_MP; RotaryEncoder_Bourns_Vertical_PEC12R-3x17F-Sxxxx; LCSC C143801
J5: 2.42" OLED; Jushuo_AFC07-S24FCA-00_1x24-1MP_P0.50_Horizontal; LCSC C262567
L1: 10u; L_1206_3216Metric; LCSC C281117
Q4: SI2302; TSOT-23; LCSC C5310967
R11, R12, R13, R14, R15, R18, R19, R20, R21, R22, R23: 10k; R_0603_1608Metric; LCSC C95204
R16: 91k; R_0603_1608Metric; Tolerance 0.1%; LCSC C326721
R17: 10k; R_0603_1608Metric; Tolerance 0.1%; LCSC C95204
R24: 1k; R_0603_1608Metric; LCSC C22548
R25: 1M; R_0603_1608Metric; LCSC C105578
SW1, SW2: SW_Push; Switch_ALPSALPINE_SKPMAME010; LCSC C115350
SW3: SW_Push; Switch_ALPSALPINE_SKPMAME010; LCSC C115350; not fitted
TP1: 12V5; TestPoint_Pad_D1.0mm
TP2: Reset; TestPoint_Pad_D1.0mm
U7: AP3012; SOT-23-5; LCSC C102618

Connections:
+3V3: C14.1, J5.5, J5.6, L1.1, R11.1, R14.1, R18.1, R19.1, R20.1, U7.4 (~SHDN), U7.5 (IN); also elsewhere on the board
+7.5V: BZ1.1 (+), R24.1; also elsewhere on the board
/MCU/BTN_A: C15.1, R12.2; also elsewhere on the board
/MCU/BTN_B: C18.1, R15.2; also elsewhere on the board
/MCU/Buzzer: R21.1; also elsewhere on the board
/MCU/ENC_A: C21.1, R23.1; also elsewhere on the board
/MCU/ENC_B: C22.1, R22.1; also elsewhere on the board
/MCU/ENC_BTN: C16.1, R13.1; also elsewhere on the board
/MCU/OLED.SCL: J5.13; also elsewhere on the board
/MCU/OLED.SDA: J5.14, J5.15; also elsewhere on the board
/User IO/12V5: C17.1, C20.1, D4.1 (K), J5.23, R16.1, TP1.1
/User IO/ENC_S1: ENC1.S1, R13.2, R18.2, SW3.2
GND: C14.2, C15.2, C16.2, C17.2, C18.2, C19.2, C20.2, C21.2, C22.2, ENC1.C, ENC1.MP, ENC1.S2, J5.1, J5.2, J5.3, J5.7, J5.8, J5.10, J5.11, J5.12, J5.16, J5.17, J5.18, J5.19, J5.20, J5.24, J5.MP (MountPin), Q4.2 (S), R17.2, R25.1, SW1.1, SW2.1, SW3.1, U7.2 (GND); also elsewhere on the board
unnamed: BZ1.2 (-), Q4.3 (D), R24.2
unnamed: D4.2 (A), L1.2, U7.1 (SW)
unnamed: ENC1.A, R19.2, R22.2
unnamed: ENC1.B, R20.2, R23.2
unnamed: J5.9, TP2.1
unnamed: J5.21, R25.2
unnamed: C19.1, J5.22
unnamed: Q4.1 (G), R21.2
unnamed: R11.2, R12.1, SW1.2
unnamed: R14.2, R15.1, SW2.2
unnamed: R16.2, R17.1, U7.3 (FB)

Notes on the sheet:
Encoder
OLED power supply
User IO
OLED
Buttons
Newvisio X242-2864KLBUG01-C24 (C5123571)
Buzzer

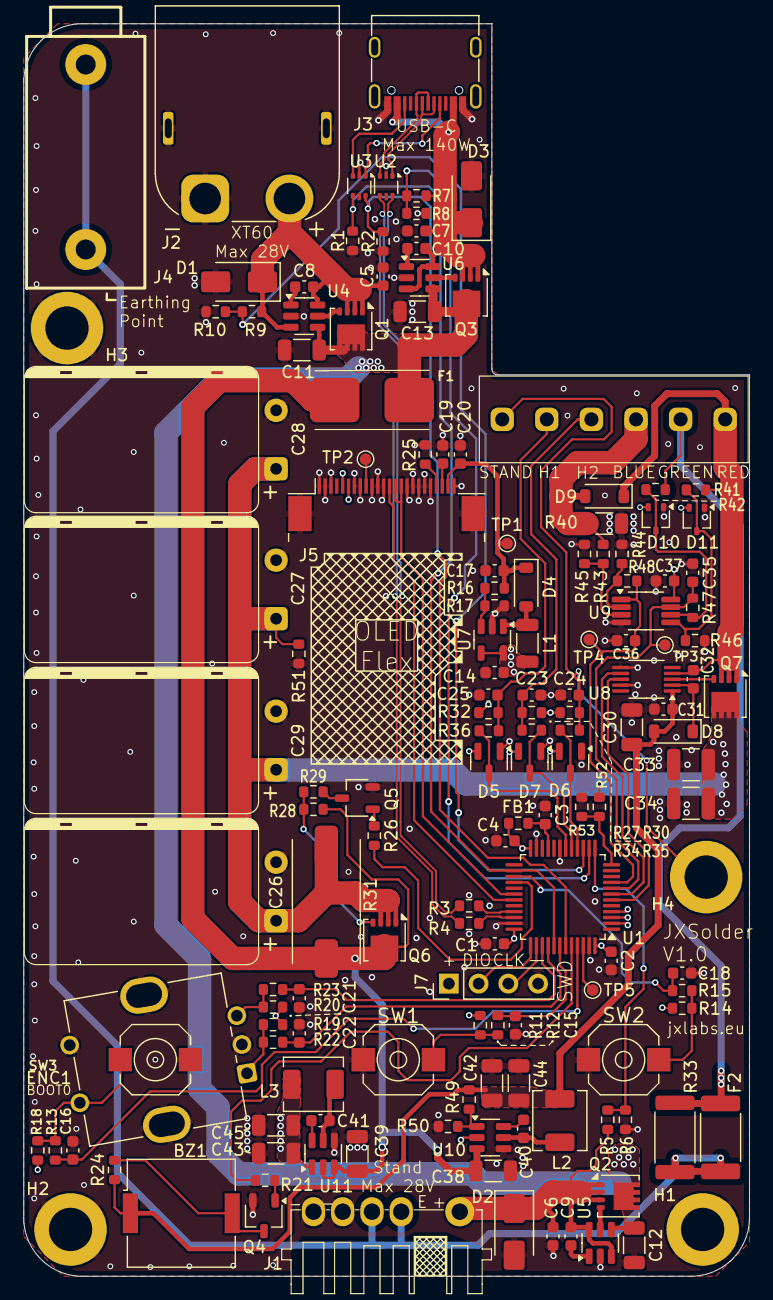
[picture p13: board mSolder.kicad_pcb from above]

Board: 4 copper layers, 62.0 x 107.0 mm, 152 parts (1 on the bottom side), 83 nets.

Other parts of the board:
QR*****: https://github.com/JX5S/jxsolder; QR_Github_Inverted

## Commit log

2025-03-01 Added files of original version for viewing
    [MCU.kicad_sch, mSolder.kicad_pcb, mSolder.kicad_sch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]
2025-03-01 Added schematic PDF
